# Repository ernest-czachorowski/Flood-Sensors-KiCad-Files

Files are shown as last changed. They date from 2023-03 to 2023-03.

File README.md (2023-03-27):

# Flood-Sensors-KiCad-Files

This repository contains KiCad files for my master's thesis IoT infrastructure, which includes water leak detection sensors. It does not include any source code as it is the intellectual property of the Nicolaus Copernicus University in Torun and cannot be published here. The infrastructure is divided into a web service made with Node.js and EJS, a PCB master board that communicates with the web service using TCP or UDP protocols, and a set of leak detection sensors that communicate with the master using the Modbus protocol and notify it when a leak is detected. The Master board sends a notification message to the web service about the leak.

### Folder Structure:

- Master - KiCad project of the Master PCB
- Slave - KiCad project of the Slave PCB
- Datasheet - datasheets of used chips/components
- KiCad_symbols - KiCad library files made by me
- Pictures - some pictures

### Master Board:

The Master board is responsible for managing communication between the web service and the Slave boards. It features an ATmega128 microcontroller, which has more RAM memory than the ATmega32 mentioned in the documentation. Communication with the web service is handled by the ENC28J60 chip, and to communicate with slaves, the MAX485 chip is used.

### Slave Board:

The Slave board detects water leaks and communicates with the Master board using the MAX485 chip. It features an LM393 chip for detecting the leak and is controlled by an ATmega32 microcontroller.

### Web Service:

The web service is built using Node.js and EJS and is responsible for receiving notification messages from the Master board about water leaks. It allows users to view the status of the system.

### License:

This project is licensed under the MIT License - see the LICENSE file for details.

### Working devices:
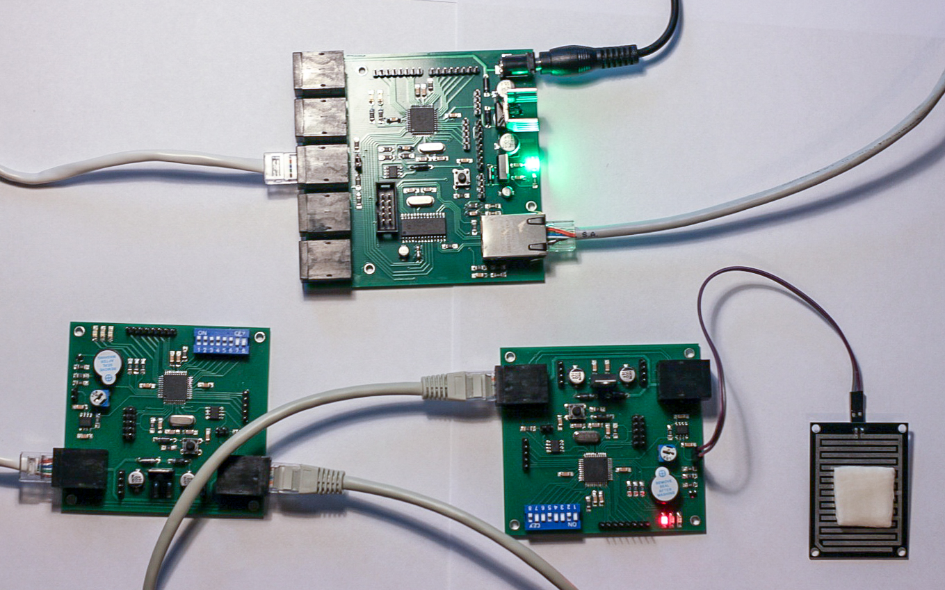
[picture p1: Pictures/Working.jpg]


### Master board:
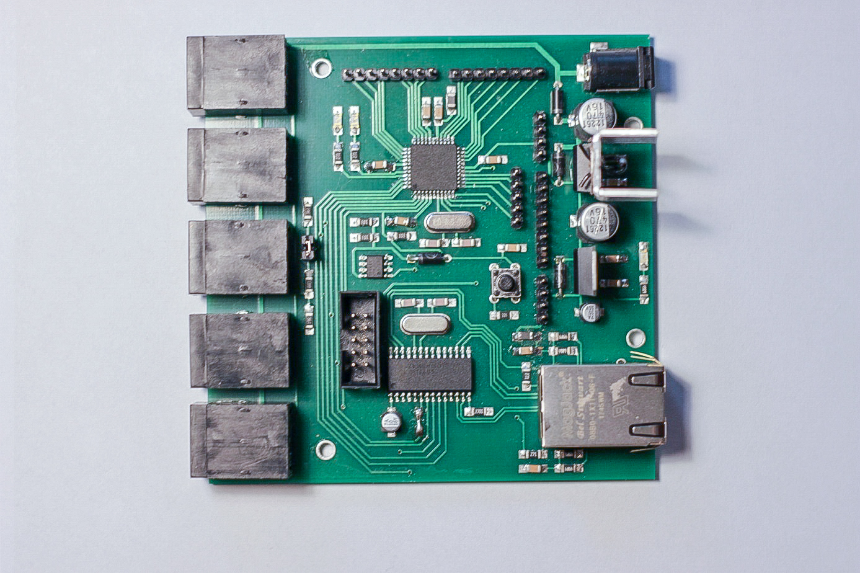
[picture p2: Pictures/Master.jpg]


### Slave board:
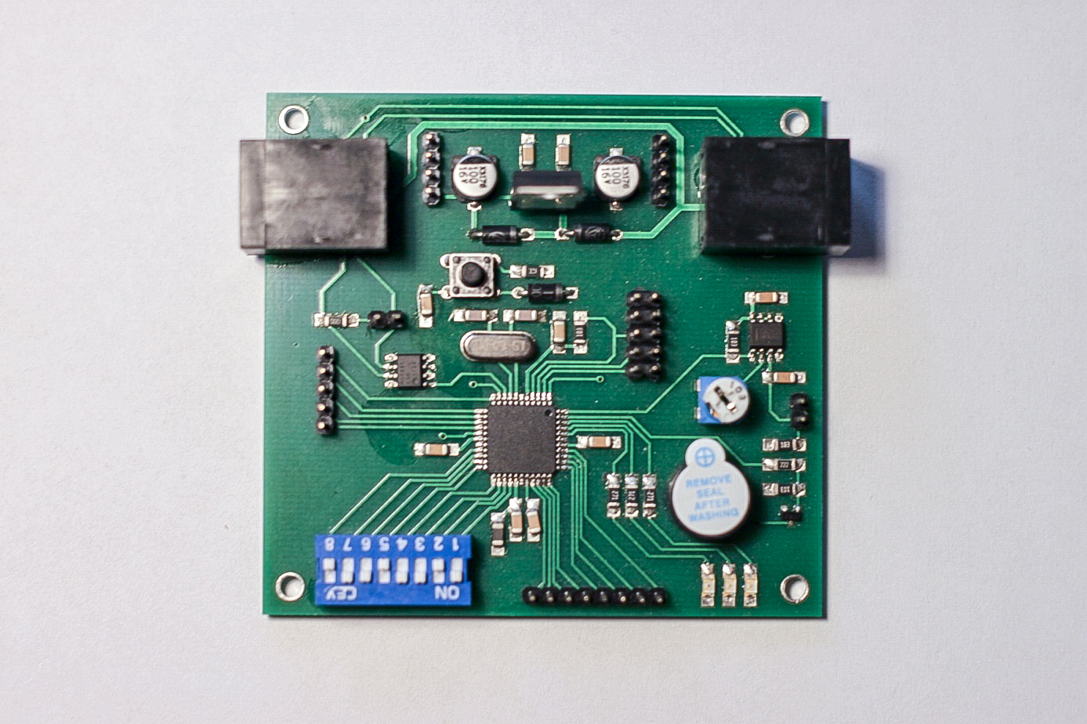
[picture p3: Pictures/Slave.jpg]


### Prototype board:
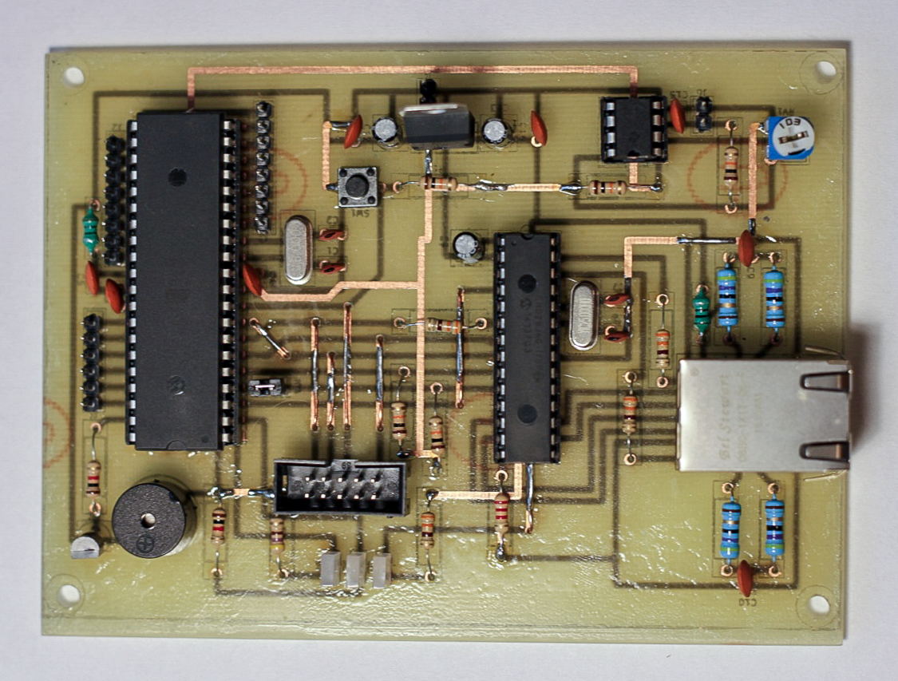
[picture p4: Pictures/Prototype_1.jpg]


### Prototype board:
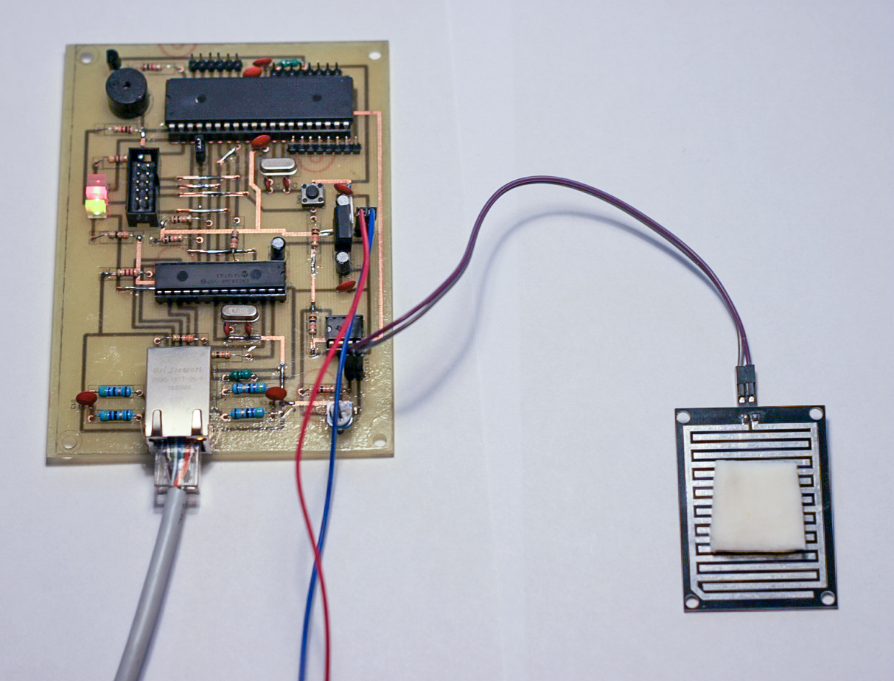
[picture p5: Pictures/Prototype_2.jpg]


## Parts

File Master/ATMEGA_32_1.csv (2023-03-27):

Reference | Value | Footprint | Datasheet
U1 | ATMEGA32-16PU | Housings_QFP:TQFP-44_10x10mm_Pitch0.8mm
U3 | ENC28J60-I/SP | Housings_SOIC:SOIC-28W_7.5x17.9mm_Pitch1.27mm
C17 | 470uF | Capacitors_SMD:CP_Elec_8x10
C19 | 10uF | Capacitors_SMD:CP_Elec_4x5.3
R18 | 50 | Resistors_SMD:R_1206_HandSoldering
D7 | GREEN | LEDs:LED_1206_HandSoldering
U5 | LF33_TO220 | TO_SOT_Packages_THT:TO-220-3_Vertical
R16 | 270 | Resistors_SMD:R_1206_HandSoldering
R17 | 270 | Resistors_SMD:R_1206_HandSoldering
R14 | 50 | Resistors_SMD:R_1206_HandSoldering
R15 | 50 | Resistors_SMD:R_1206_HandSoldering
C15 | 100nF | Capacitors_SMD:C_1206_HandSoldering
R12 | 50 | Resistors_SMD:R_1206_HandSoldering
R13 | 50 | Resistors_SMD:R_1206_HandSoldering
C14 | 100nF | Capacitors_SMD:C_1206_HandSoldering
L2 | 10uH | Inductors_SMD:L_1206_HandSoldering
Y2 | 25MHZ | Crystals:Crystal_HC49-U_Vertical
C9 | 22pF | Capacitors_SMD:C_1206_HandSoldering
C10 | 22pF | Capacitors_SMD:C_1206_HandSoldering
R8 | 10K | Resistors_SMD:R_1206_HandSoldering
R9 | 10K | Resistors_SMD:R_1206_HandSoldering
C11 | 10uF | Capacitors_SMD:CP_Elec_4x5.3
R11 | 2K7 | Resistors_SMD:R_1206_HandSoldering
C18 | 100nF | Capacitors_SMD:C_1206_HandSoldering
C16 | 100nF | Capacitors_SMD:C_1206_HandSoldering
C8 | 100nF | Capacitors_SMD:C_1206_HandSoldering
Y1 | 16MHZ | Crystals:Crystal_HC49-U_Vertical
C2 | 22pF | Capacitors_SMD:C_1206_HandSoldering
C3 | 22pF | Capacitors_SMD:C_1206_HandSoldering
CON1 | AVR-ISP-10 | Pin_Headers:Pin_Header_Straight_2x05_Pitch2.54mm
R2 | 10K | Resistors_SMD:R_1206_HandSoldering
SW1 | SW_Push | Buttons_Switches_THT:SW_PUSH_6mm_h13mm
J2 | Conn_01x08 | Pin_Headers:Pin_Header_Straight_1x08_Pitch2.54mm
C4 | 100nF | Capacitors_SMD:C_1206_HandSoldering
L1 | 10uH | Inductors_SMD:L_1206_HandSoldering
D2 | RED | LEDs:LED_1206_HandSoldering
D3 | BLUE | LEDs:LED_1206_HandSoldering
R3 | 270 | Resistors_SMD:R_1206_HandSoldering
R4 | 270 | Resistors_SMD:R_1206_HandSoldering
J13 | RJ45-08B01X1T06-F | Connectors:RJ45-08B01X1T06-F
R10 | 270 | Resistors_SMD:R_1206_HandSoldering
U2 | MAX485E | Housings_SOIC:SOIC-8_3.9x4.9mm_Pitch1.27mm
C13 | 100nF | Capacitors_SMD:C_1206_HandSoldering
C12 | 470uF | Capacitors_SMD:CP_Elec_8x10
J6 | Conn_01x03 | Connectors:BARREL_JACK
JP1 | Jumper | Pin_Headers:Pin_Header_Straight_1x02_Pitch2.54mm
R6 | 120 | Resistors_SMD:R_1206_HandSoldering
R5 | 560 | Resistors_SMD:R_1206_HandSoldering
R7 | 560 | Resistors_SMD:R_1206_HandSoldering
C5 | 100nF | Capacitors_SMD:C_1206_HandSoldering
C6 | 100nF | Capacitors_SMD:C_1206_HandSoldering
C7 | 100nF | Capacitors_SMD:C_1206_HandSoldering
J1 | Conn_01x08 | Pin_Headers:Pin_Header_Straight_1x08_Pitch2.54mm
U4 | L7805 | TO_SOT_Packages_THT:TO-220-3_Vertical
D6 | 1N4004 | Diodes_THT:D_DO-35_SOD27_P7.62mm_Horizontal
D5 | 1N4004 | Diodes_THT:D_DO-35_SOD27_P7.62mm_Horizontal
D4 | 1N4004 | Diodes_THT:D_DO-35_SOD27_P7.62mm_Horizontal
R1 | 330 | Resistors_SMD:R_1206_HandSoldering
C1 | 100nF | Capacitors_SMD:C_1206_HandSoldering
J3 | Conn_01x05 | Pin_Headers:Pin_Header_Straight_1x05_Pitch2.54mm
J10 | Conn_01x04 | Pin_Headers:Pin_Header_Straight_1x04_Pitch2.54mm
J12 | Conn_01x04 | Pin_Headers:Pin_Header_Straight_1x04_Pitch2.54mm
J7 | Conn_01x08 | Pin_Headers:Pin_Header_Straight_1x08_Pitch2.54mm
J4 | RJ45 | Connectors:RJ45_8
J5 | RJ45 | Connectors:RJ45_8
J9 | RJ45 | Connectors:RJ45_8
J11 | RJ45 | Connectors:RJ45_8
D1 | 1N4004 | Diodes_THT:D_DO-35_SOD27_P7.62mm_Horizontal
C20 | 100nF | Capacitors_SMD:C_1206_HandSoldering
J8 | RJ45 | Connectors:RJ45_8

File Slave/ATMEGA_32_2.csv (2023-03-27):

Reference | Value | Footprint | Datasheet
U1 | ATMEGA32-16PU | Housings_QFP:TQFP-44_10x10mm_Pitch0.8mm
C14 | 100uF | Capacitors_SMD:CP_Elec_6.3x5.3
C13 | 100nF | Capacitors_SMD:C_1206_HandSoldering
C8 | 100nF | Capacitors_SMD:C_1206_HandSoldering
Y1 | 16MHZ | Crystals:Crystal_HC49-U_Vertical
C2 | 22pF | Capacitors_SMD:C_1206_HandSoldering
C3 | 22pF | Capacitors_SMD:C_1206_HandSoldering
CON1 | AVR-ISP-10 | Pin_Headers:Pin_Header_Straight_2x05_Pitch2.54mm
R2 | 10K | Resistors_SMD:R_1206_HandSoldering
SW1 | SW_Push | Buttons_Switches_THT:SW_PUSH_6mm_h13mm
C4 | 100nF | Capacitors_SMD:C_1206_HandSoldering
L1 | 10uH | Inductors_SMD:L_1206_HandSoldering
D2 | RED | LEDs:LED_1206_HandSoldering
D3 | GREEN | LEDs:LED_1206_HandSoldering
R3 | 270 | Resistors_SMD:R_1206_HandSoldering
R4 | 270 | Resistors_SMD:R_1206_HandSoldering
U2 | MAX485E | Housings_SOIC:SOIC-8_3.9x4.9mm_Pitch1.27mm
C12 | 330nF | Capacitors_SMD:C_1206_HandSoldering
C11 | 100uF | Capacitors_SMD:CP_Elec_6.3x5.3
JP1 | Jumper | Pin_Headers:Pin_Header_Straight_1x02_Pitch2.54mm
R6 | 120 | Resistors_SMD:R_1206_HandSoldering
C5 | 100nF | Capacitors_SMD:C_1206_HandSoldering
C6 | 100nF | Capacitors_SMD:C_1206_HandSoldering
C7 | 100nF | Capacitors_SMD:C_1206_HandSoldering
J1 | Conn_01x08 | Pin_Headers:Pin_Header_Straight_1x08_Pitch2.54mm
J2 | Conn_01x05 | Pin_Headers:Pin_Header_Straight_1x05_Pitch2.54mm
U4 | L7805 | TO_SOT_Packages_THT:TO-220-3_Vertical
U3 | LM393 | Housings_SOIC:SOIC-8_3.9x4.9mm_Pitch1.27mm
R8 | 10K | Resistors_SMD:R_1206_HandSoldering
R7 | 10K | Resistors_SMD:R_1206_HandSoldering
RV1 | 10K | Potentiometers:Potentiometer_Trimmer_ACP_CA6v_Horizontal
C9 | 100nF | Capacitors_SMD:C_1206_HandSoldering
J3 | Conn_01x02 | Pin_Headers:Pin_Header_Straight_1x02_Pitch2.54mm
BZ1 | Buzzer | Buzzers_Beepers:Buzzer_12x9.5RM7.6
R9 | 2K2 | Resistors_SMD:R_1206_HandSoldering
Q1 | BC847 | TO_SOT_Packages_SMD:SOT-23
SW2 | SW_DIP_x08 | Buttons_Switches_THT:SW_DIP_x8_W7.62mm_Slide
R1 | 330 | Resistors_SMD:R_1206_HandSoldering
C1 | 100nF | Capacitors_SMD:C_1206_HandSoldering
D1 | 1N4004 | Diodes_THT:D_DO-35_SOD27_P7.62mm_Horizontal
D6 | 1N4004 | Diodes_THT:D_DO-35_SOD27_P7.62mm_Horizontal
D5 | 1N4004 | Diodes_THT:D_DO-35_SOD27_P7.62mm_Horizontal
J6 | Conn_01x04 | Pin_Headers:Pin_Header_Straight_1x04_Pitch2.54mm
J7 | Conn_01x04 | Pin_Headers:Pin_Header_Straight_1x04_Pitch2.54mm
R5 | 270 | Resistors_SMD:R_1206_HandSoldering
D4 | BLUE | LEDs:LED_1206_HandSoldering
C10 | 100nF | Capacitors_SMD:C_1206_HandSoldering
R10 | 10K | Resistors_SMD:R_1206_HandSoldering
J5 | RJ45 | Connectors:RJ45_8
J4 | RJ45 | Connectors:RJ45_8

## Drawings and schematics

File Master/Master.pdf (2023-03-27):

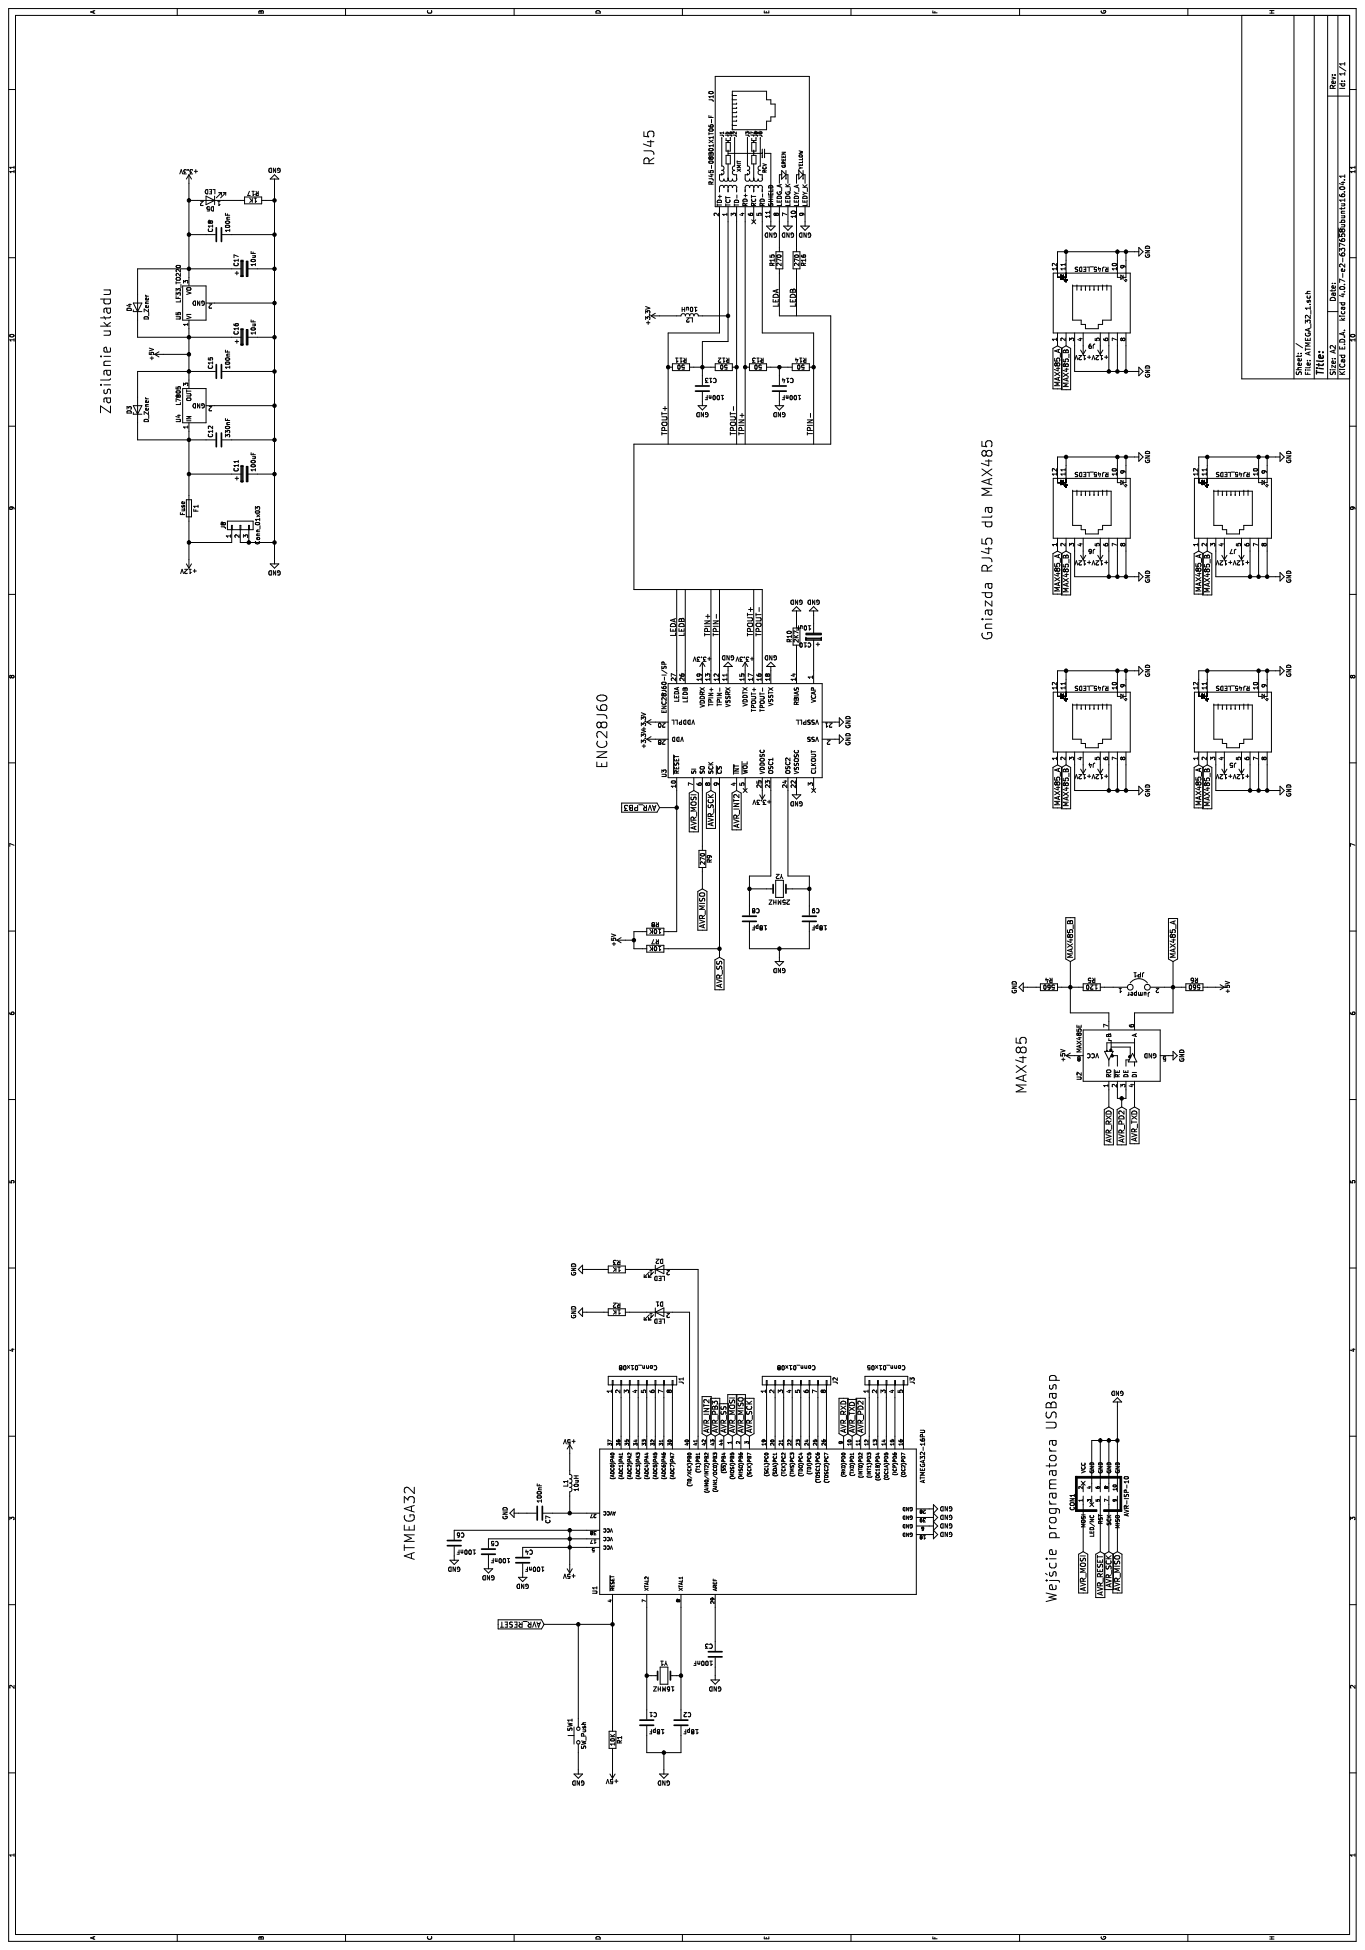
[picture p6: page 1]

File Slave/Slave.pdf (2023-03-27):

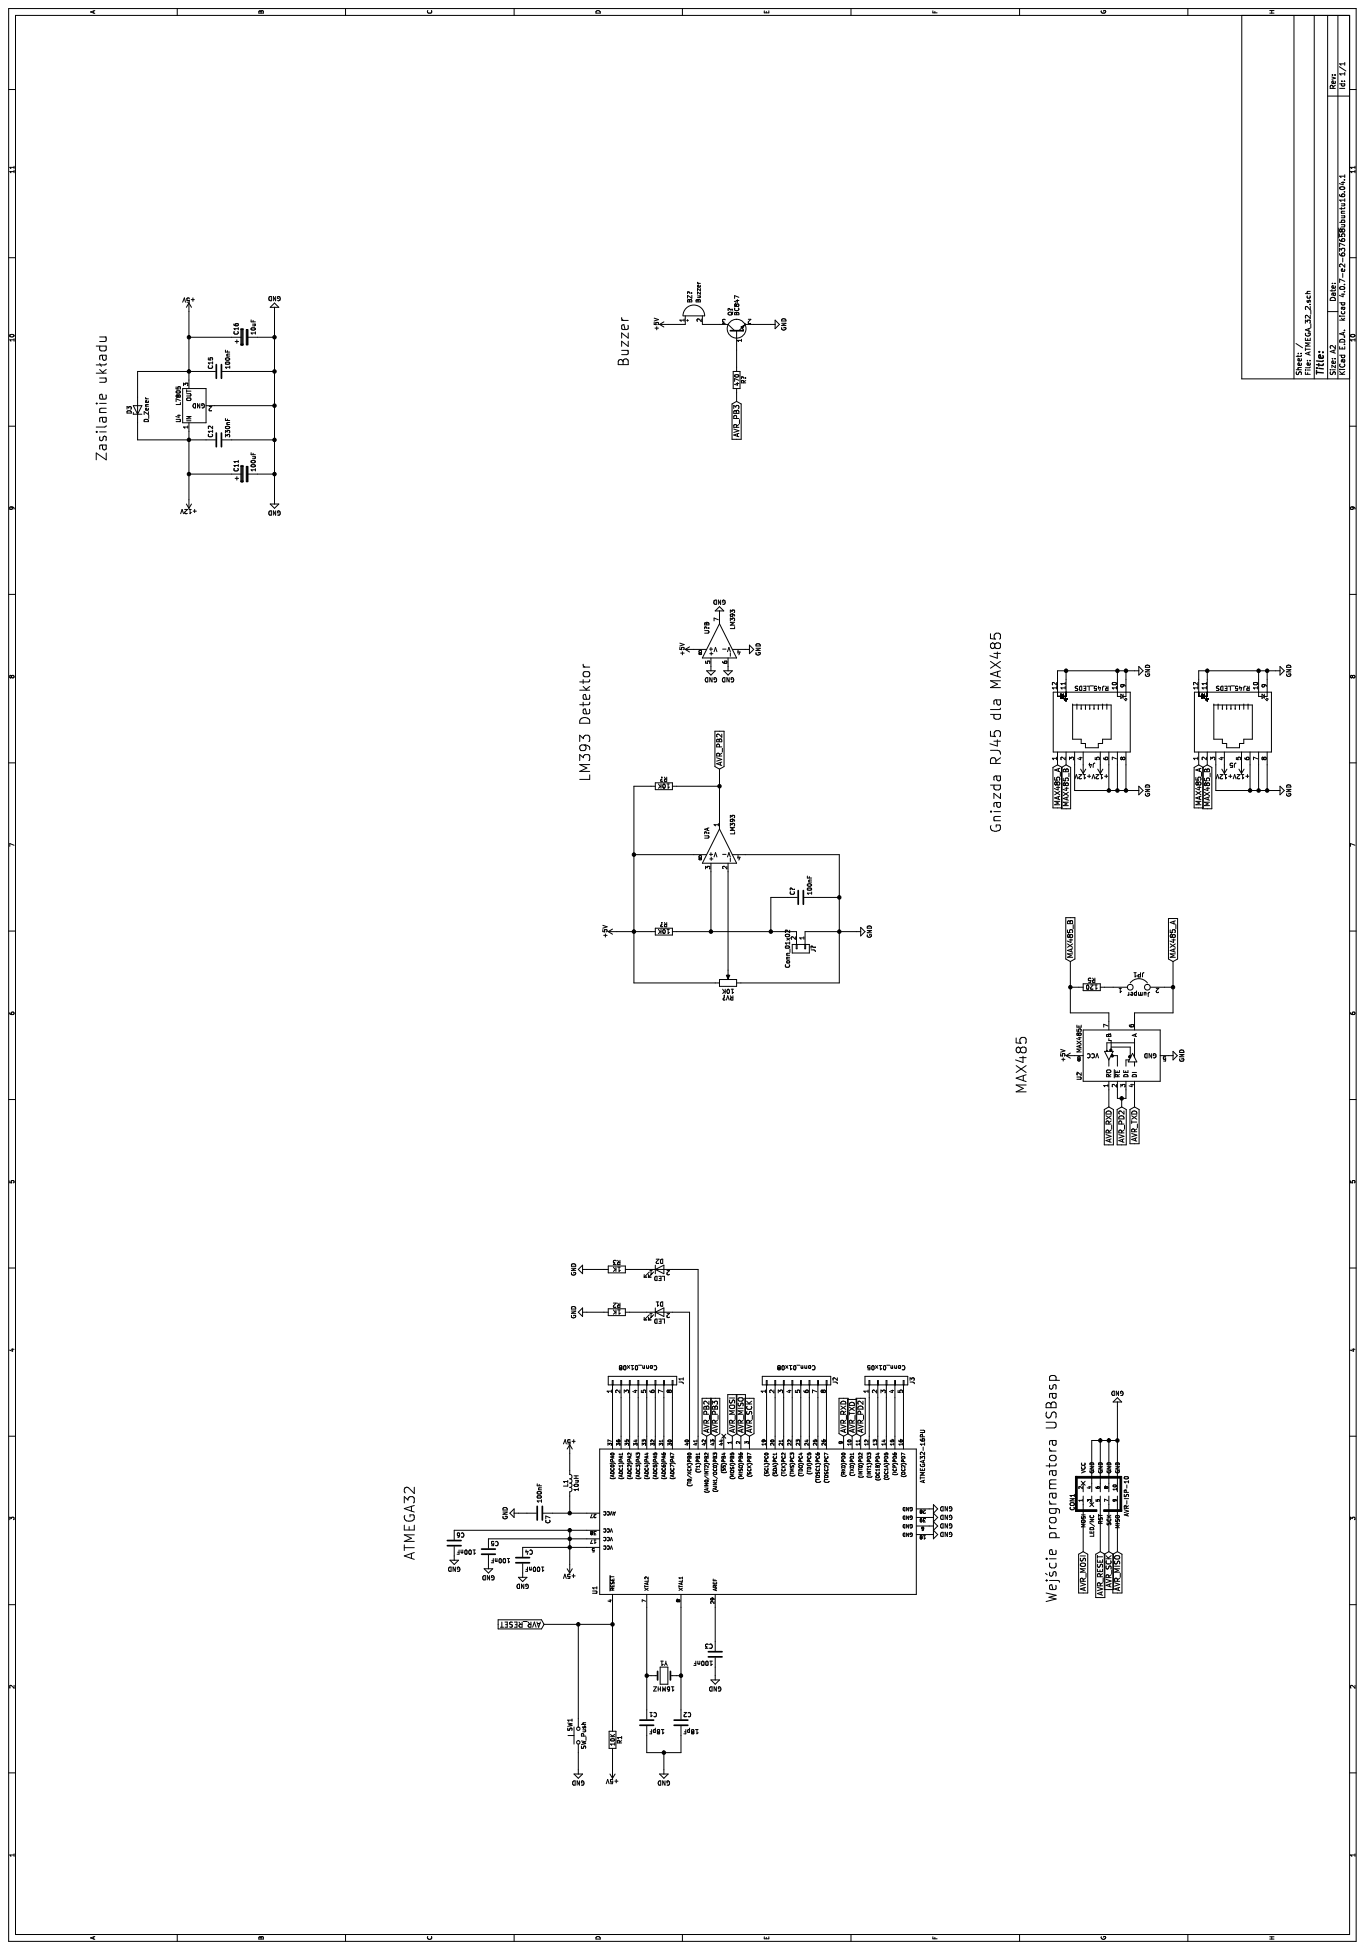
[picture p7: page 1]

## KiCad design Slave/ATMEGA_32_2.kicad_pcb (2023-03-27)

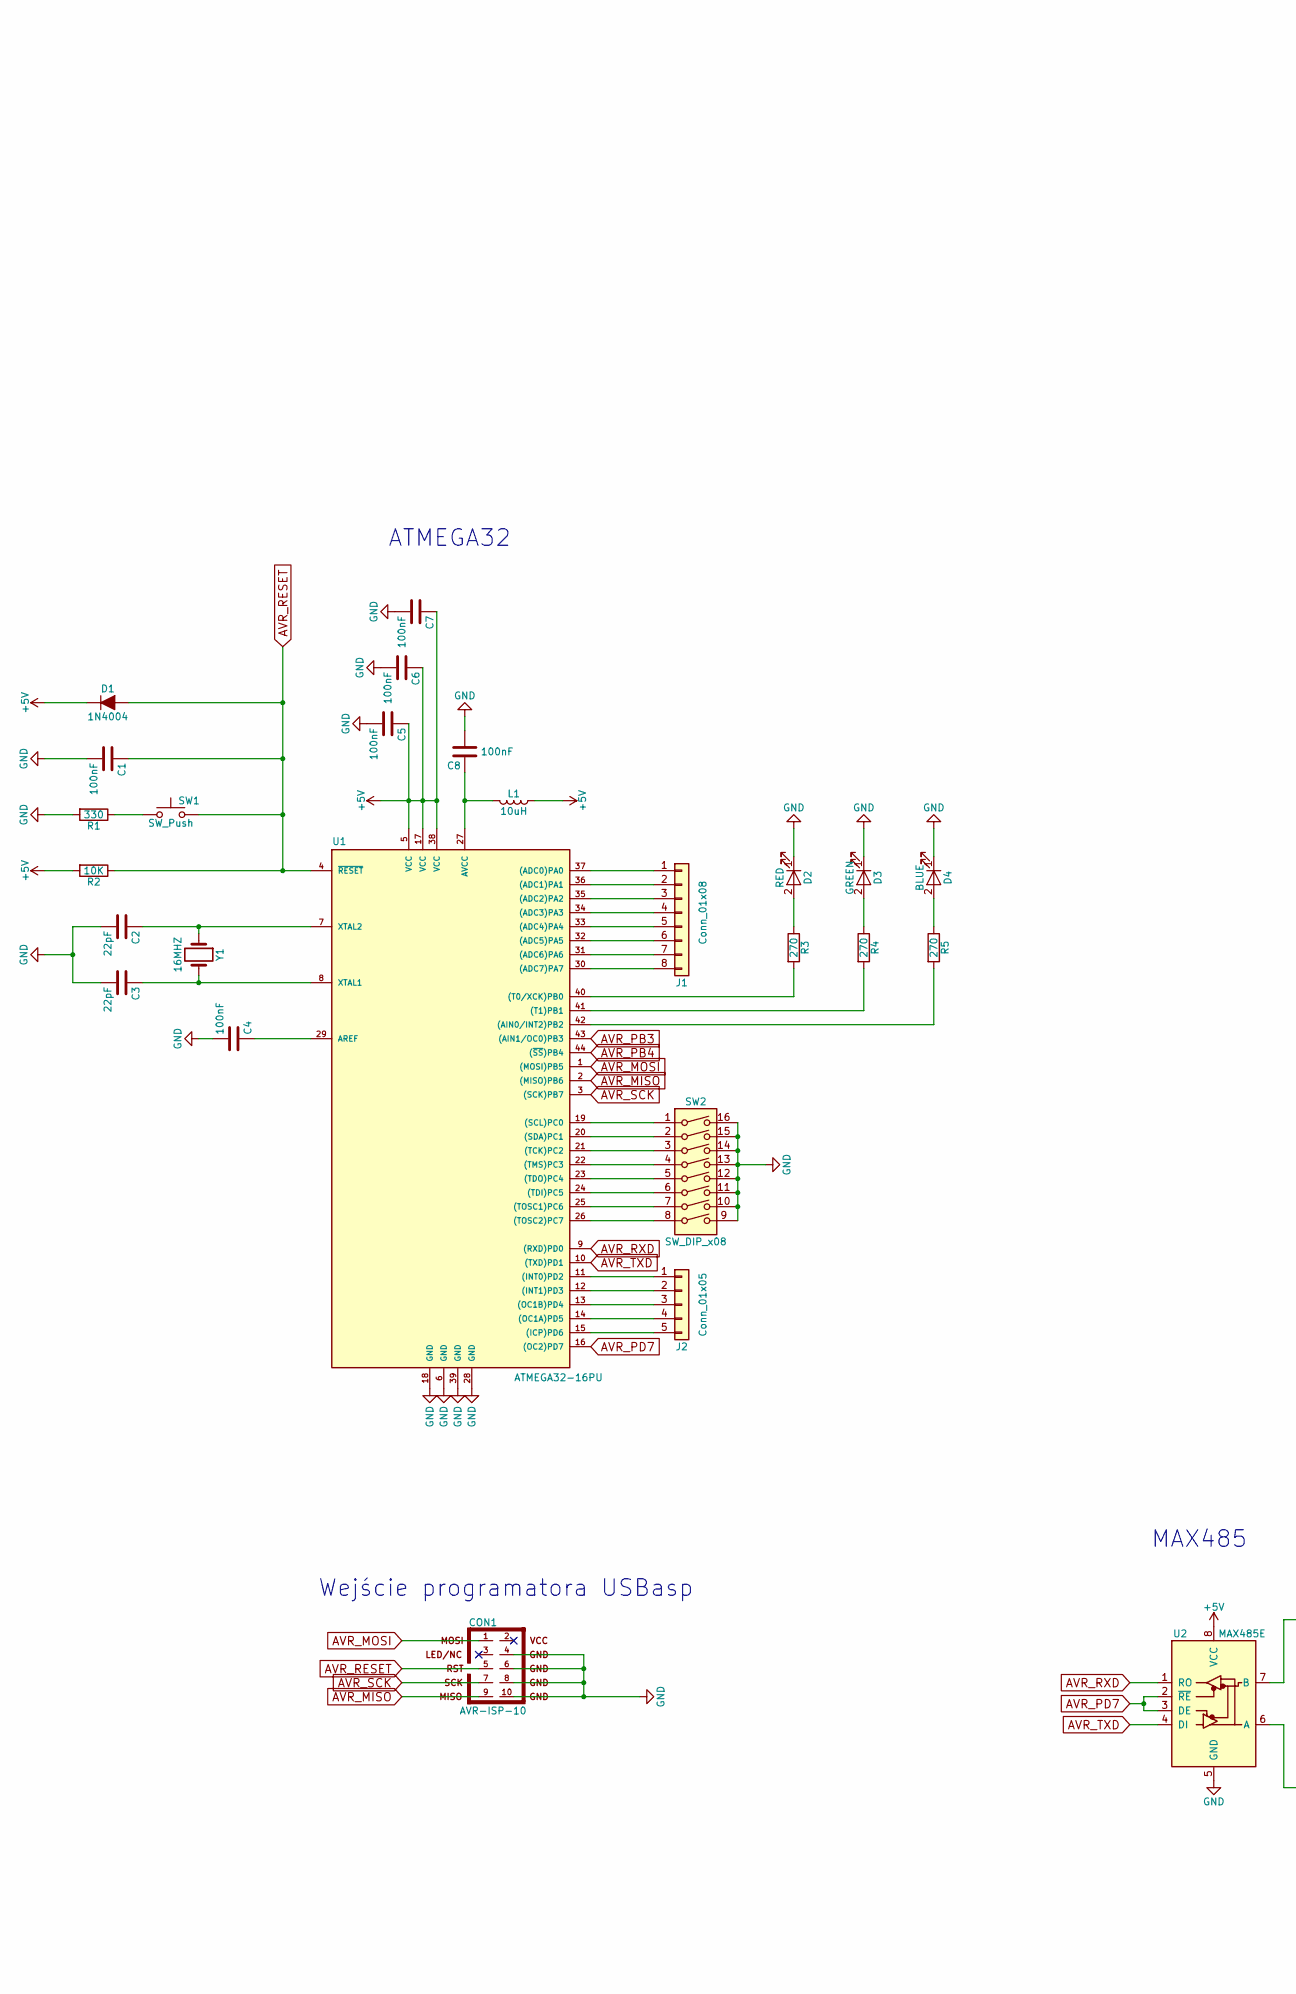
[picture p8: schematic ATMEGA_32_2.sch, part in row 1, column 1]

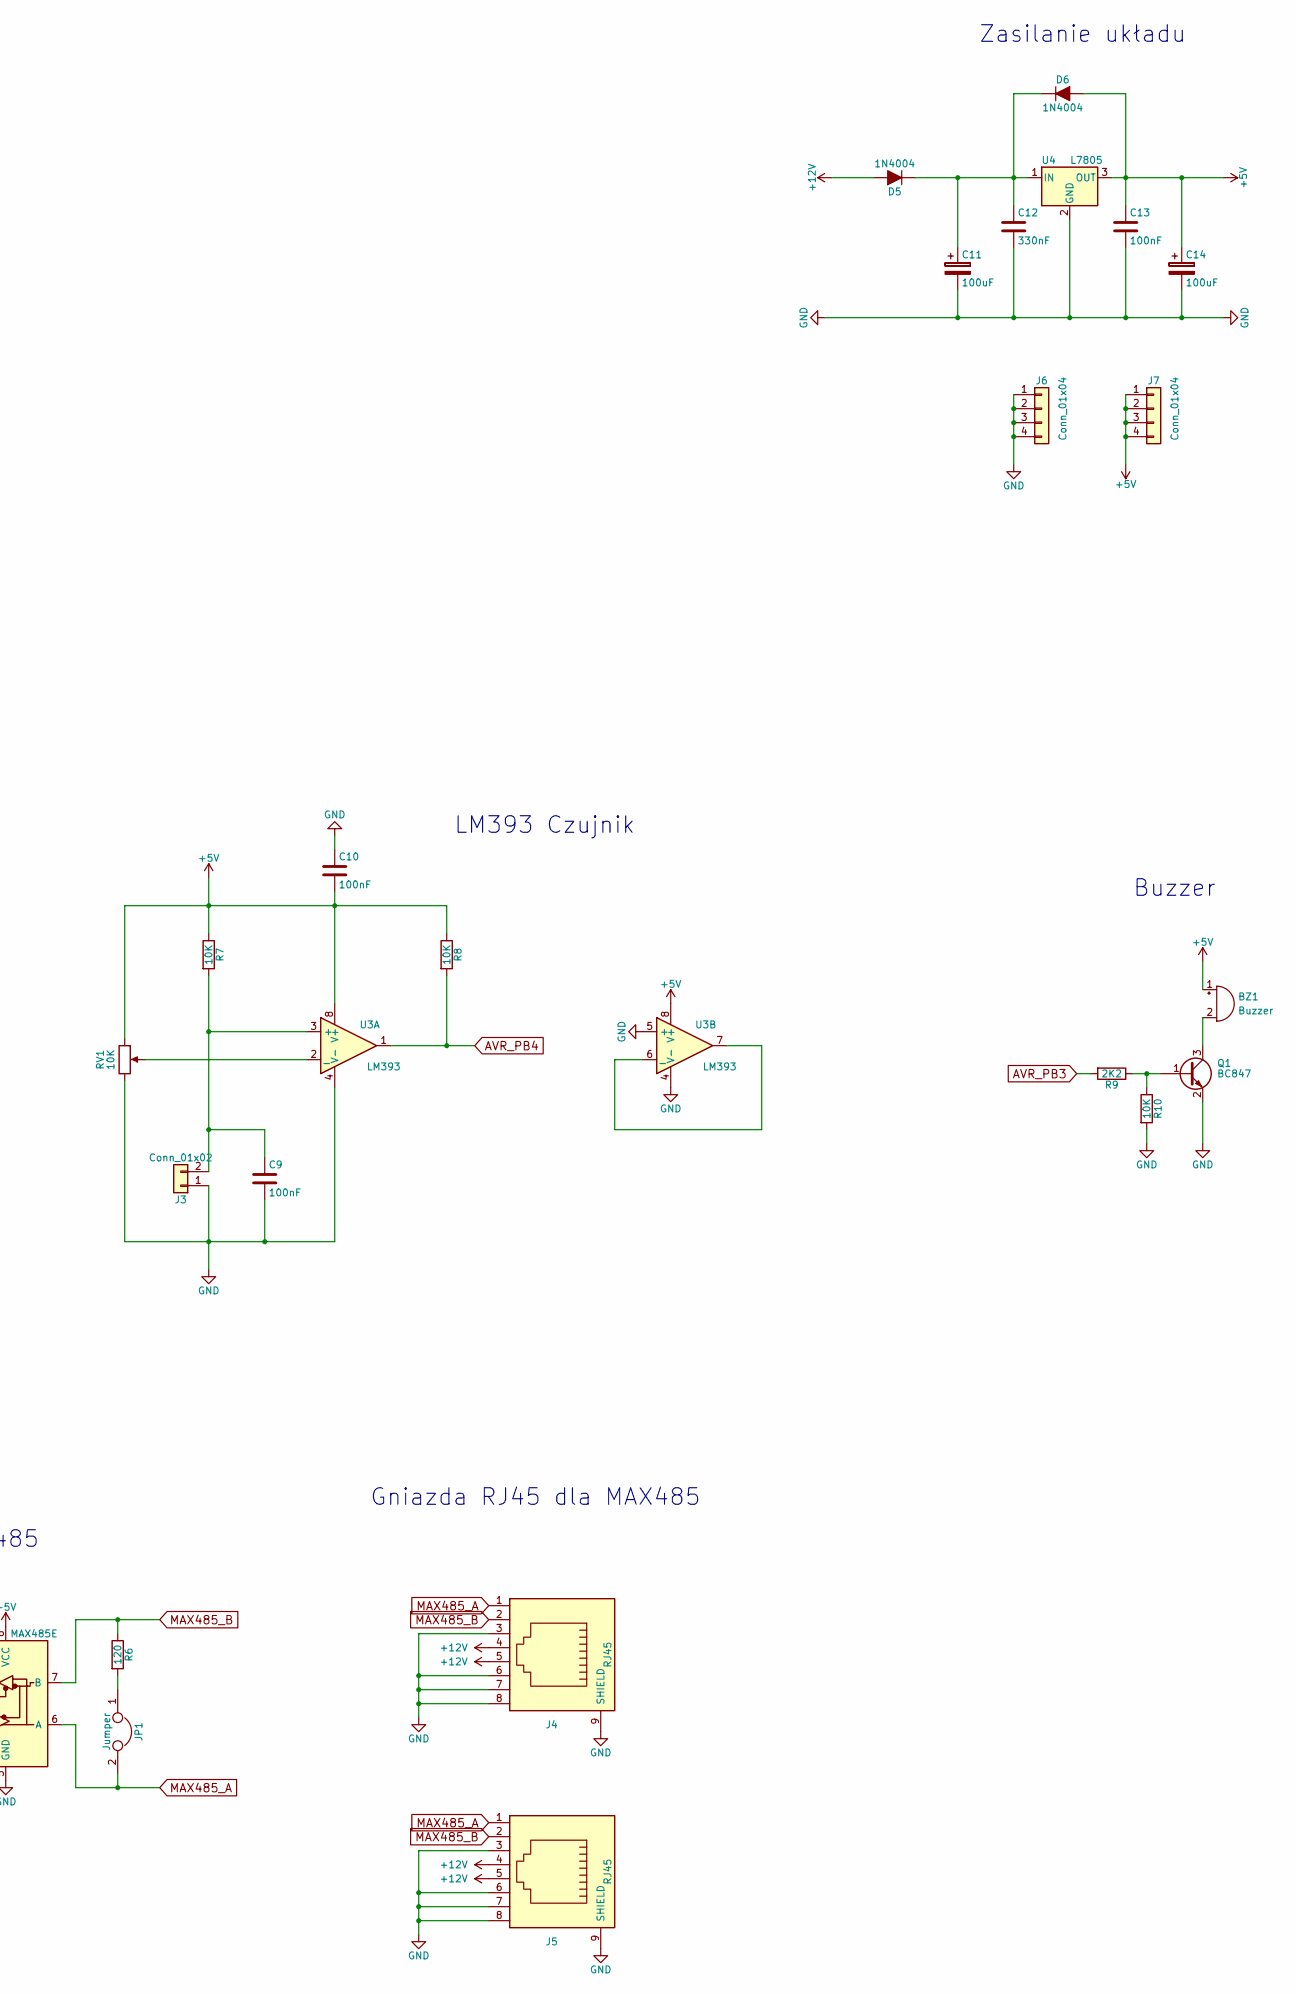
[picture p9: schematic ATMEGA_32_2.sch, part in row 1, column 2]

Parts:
BZ1: Buzzer; Buzzer_12x9.5RM7.6
C1, C4, C5, C6, C7, C8, C9, C10, C13: 100nF; C_1206_HandSoldering
C2, C3: 22pF; C_1206_HandSoldering
C11, C14: 100uF; CP_Elec_6.3x5.3
C12: 330nF; C_1206_HandSoldering
CON1: AVR-ISP-10; Pin_Header_Straight_2x05_Pitch2.54mm
D1, D5, D6: 1N4004; D_DO-35_SOD27_P7.62mm_Horizontal
D2: RED; LED_1206_HandSoldering
D3: GREEN; LED_1206_HandSoldering
D4: BLUE; LED_1206_HandSoldering
J1: Conn_01x08; Pin_Header_Straight_1x08_Pitch2.54mm
J2: Conn_01x05; Pin_Header_Straight_1x05_Pitch2.54mm
J3: Conn_01x02; Pin_Header_Straight_1x02_Pitch2.54mm
J4, J5: RJ45; RJ45_8
J6, J7: Conn_01x04; Pin_Header_Straight_1x04_Pitch2.54mm
JP1: Jumper; Pin_Header_Straight_1x02_Pitch2.54mm
L1: 10uH; L_1206_HandSoldering
Q1: BC847; SOT-23
R1: 330; R_1206_HandSoldering
R2, R7, R8, R10: 10K; R_1206_HandSoldering
R3, R4, R5: 270; R_1206_HandSoldering
R6: 120; R_1206_HandSoldering
R9: 2K2; R_1206_HandSoldering
RV1: 10K; Potentiometer_Trimmer_ACP_CA6v_Horizontal
SW1: SW_Push; SW_PUSH_6mm_h13mm
SW2: SW_DIP_x08; SW_DIP_x8_W7.62mm_Slide
U1: ATMEGA32-16PU; TQFP-44_10x10mm_Pitch0.8mm
U2: MAX485E; SOIC-8_3.9x4.9mm_Pitch1.27mm
U3: LM393; SOIC-8_3.9x4.9mm_Pitch1.27mm
U4: L7805; TO-220-3_Vertical
Y1: 16MHZ; Crystal_HC49-U_Vertical

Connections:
+5V: BZ1.1 (-), C5.1, C6.1, C7.1, C10.2, C13.1, C14.1, D1.1 (K), D6.2 (A), J7.1, J7.2, J7.3, J7.4, L1.1, R2.2, R7.1, R8.1, RV1.1, U1.5 (VCC), U1.17 (VCC), U1.38 (VCC), U2.8 (VCC), U3.8 (V+), U4.3 (OUT)
+12V: D5.2 (A), J4.4, J4.5, J5.4, J5.5
AVR_MISO: CON1.9, U1.2 ((MISO)PB6)
AVR_MOSI: CON1.1, U1.1 ((MOSI)PB5)
AVR_PB3: R9.2, U1.43 ((AIN1/OC0)PB3)
AVR_PB4: R8.2, U1.44 ((~SS~)PB4), U3.1
AVR_PD7: U1.16 ((OC2)PD7), U2.2 (~RE), U2.3 (DE)
AVR_RESET: C1.1, CON1.5, D1.2 (A), R2.1, SW1.2, U1.4 (~RESET)
AVR_RXD: U1.9 ((RXD)PD0), U2.1 (RO)
AVR_SCK: CON1.7, U1.3 ((SCK)PB7)
AVR_TXD: U1.10 ((TXD)PD1), U2.4 (DI)
GND: C1.2, C2.2, C3.2, C4.2, C5.2, C6.2, C7.2, C8.2, C9.2, C10.1, C11.2, C12.2, C13.2, C14.2, CON1.4, CON1.6, CON1.8, CON1.10, D2.1 (K), D3.1 (K), D4.1 (K), J3.1, J4.3, J4.6, J4.7, J4.8, J4.9 (SHIELD), J5.3, J5.6, J5.7, J5.8, J5.9 (SHIELD), J6.1, J6.2, J6.3, J6.4, Q1.2 (E), R1.2, R10.2, RV1.3, SW2.9, SW2.10, SW2.11, SW2.12, SW2.13, SW2.14, SW2.15, SW2.16, U1.6 (GND), U1.18 (GND), U1.28 (GND), U1.39 (GND), U2.5 (GND), U3.4 (V-), U3.5 (+), U4.2 (GND)
MAX485_A: J4.1, J5.1, JP1.2, U2.6 (A)
MAX485_B: J4.2, J5.2, R6.1, U2.7 (B)
unnamed: BZ1.2 (+), Q1.3 (C)
unnamed: C2.1, U1.7 (XTAL2), Y1.1
unnamed: C3.1, U1.8 (XTAL1), Y1.2
unnamed: C4.1, U1.29 (AREF)
unnamed: C8.1, L1.2, U1.27 (AVCC)
unnamed: C9.1, J3.2, R7.2, U3.3 (+)
unnamed: C11.1, C12.1, D5.1 (K), D6.1 (K), U4.1 (IN)
unnamed: D2.2 (A), R3.1
unnamed: D3.2 (A), R4.1
unnamed: D4.2 (A), R5.1
unnamed: J1.1, U1.37 ((ADC0)PA0)
unnamed: J1.2, U1.36 ((ADC1)PA1)
unnamed: J1.3, U1.35 ((ADC2)PA2)
unnamed: J1.4, U1.34 ((ADC3)PA3)
unnamed: J1.5, U1.33 ((ADC4)PA4)
unnamed: J1.6, U1.32 ((ADC5)PA5)
unnamed: J1.7, U1.31 ((ADC6)PA6)
unnamed: J1.8, U1.30 ((ADC7)PA7)
unnamed: J2.1, U1.11 ((INT0)PD2)
unnamed: J2.2, U1.12 ((INT1)PD3)
unnamed: J2.3, U1.13 ((OC1B)PD4)
unnamed: J2.4, U1.14 ((OC1A)PD5)
unnamed: J2.5, U1.15 ((ICP)PD6)
unnamed: JP1.1, R6.2
unnamed: Q1.1 (B), R9.1, R10.1
unnamed: R1.1, SW1.1
unnamed: R3.2, U1.40 ((T0/XCK)PB0)
unnamed: R4.2, U1.41 ((T1)PB1)
unnamed: R5.2, U1.42 ((AIN0/INT2)PB2)
unnamed: RV1.2, U3.2 (_)
unnamed: SW2.1, U1.19 ((SCL)PC0)
unnamed: SW2.2, U1.20 ((SDA)PC1)
unnamed: SW2.3, U1.21 ((TCK)PC2)
unnamed: SW2.4, U1.22 ((TMS)PC3)
unnamed: SW2.5, U1.23 ((TDO)PC4)
unnamed: SW2.6, U1.24 ((TDI)PC5)
unnamed: SW2.7, U1.25 ((TOSC1)PC6)
unnamed: SW2.8, U1.26 ((TOSC2)PC7)
unnamed: U3.6 (_), U3.7

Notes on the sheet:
Wejście programatora USBasp
ATMEGA32
Zasilanie układu
MAX485
Gniazda RJ45 dla MAX485
LM393 Czujnik
Buzzer

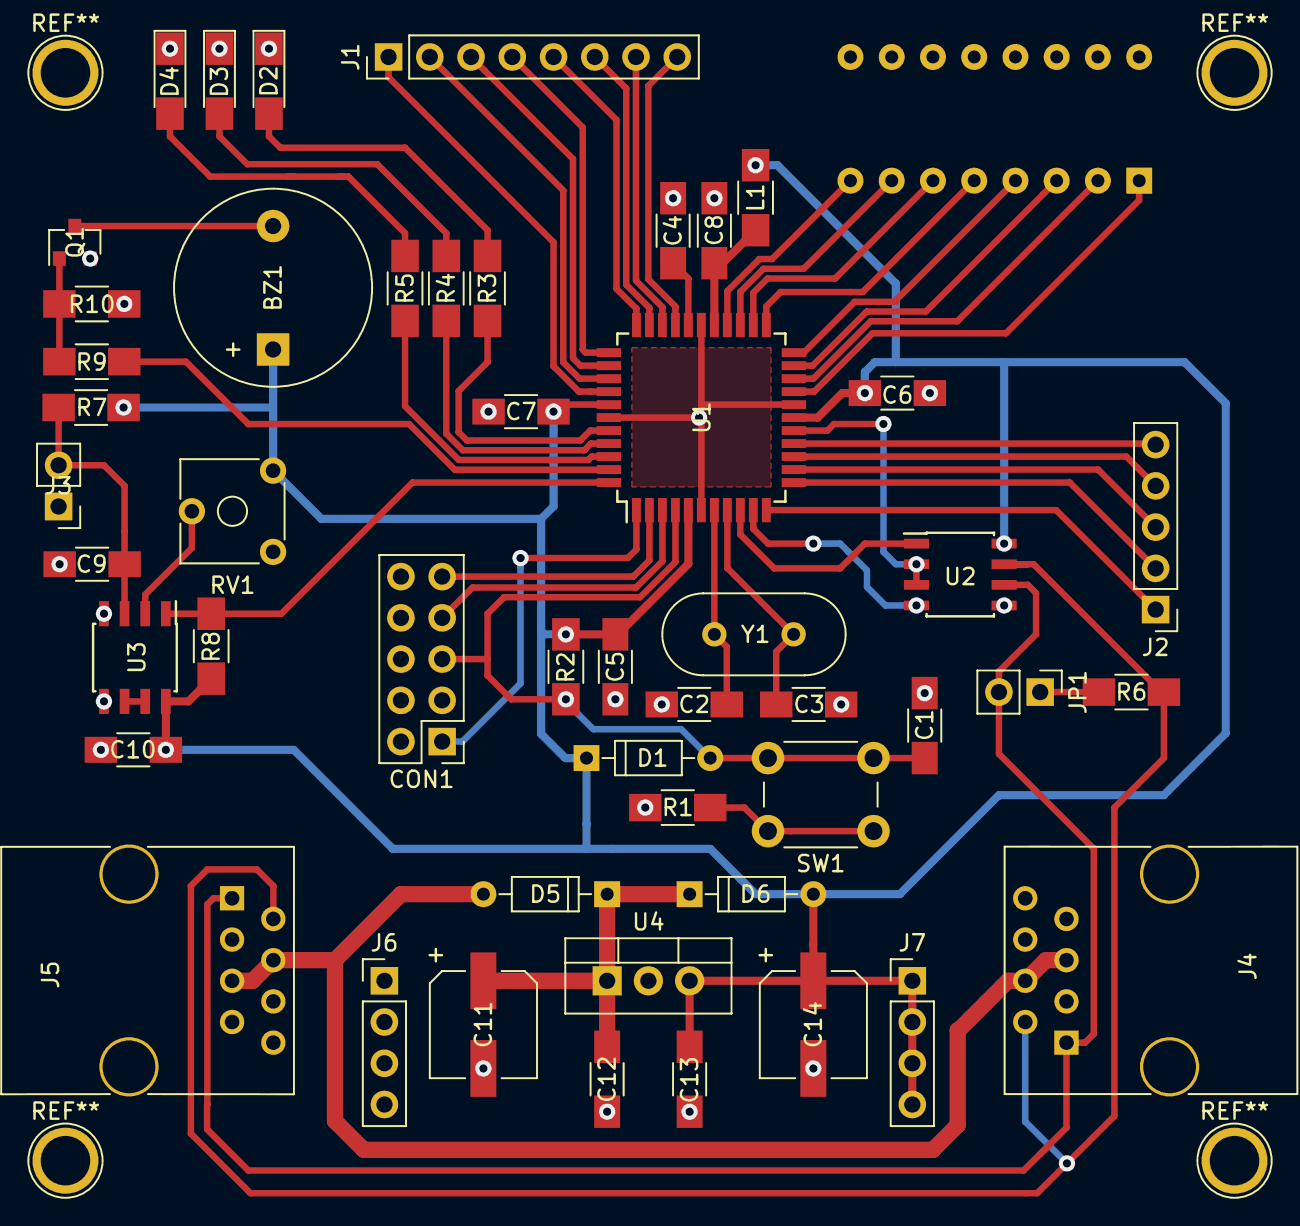
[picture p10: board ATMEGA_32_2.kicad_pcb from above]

Board: 2 copper layers, 50 parts (1 on the bottom side), 53 nets.
